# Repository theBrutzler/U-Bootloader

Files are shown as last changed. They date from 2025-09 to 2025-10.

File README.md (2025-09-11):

# U-Bootloader

Learnin PCB with many Sensors. Made in Twitchstream. SUB Tember board!

I created a board!
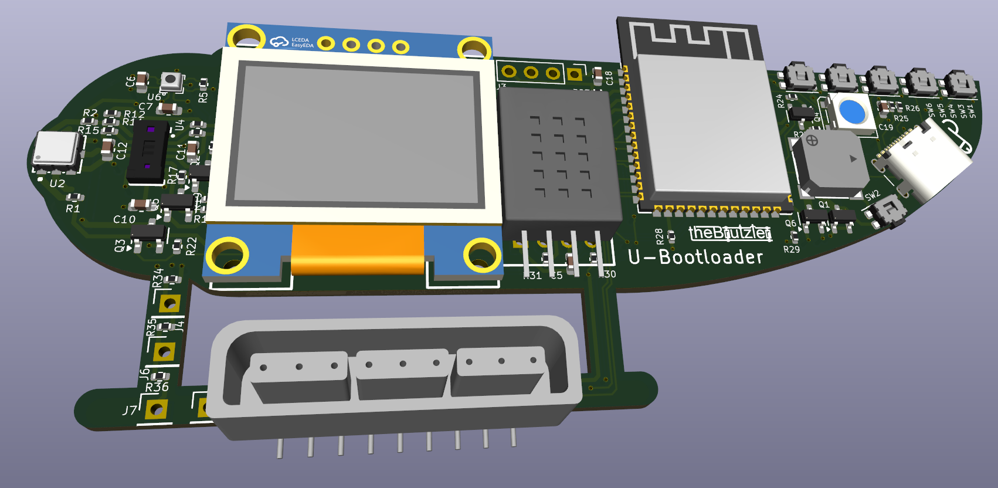
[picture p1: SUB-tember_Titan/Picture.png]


with interesting backside XD

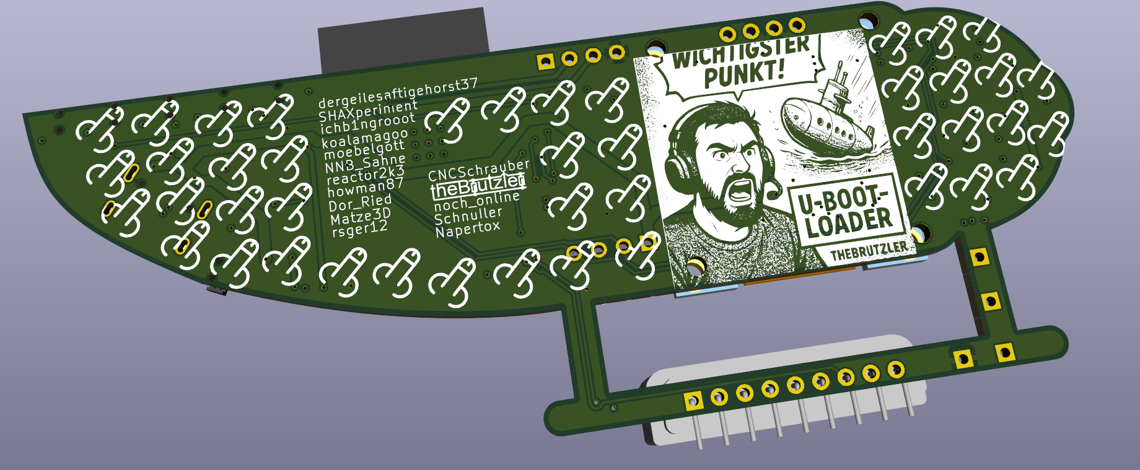
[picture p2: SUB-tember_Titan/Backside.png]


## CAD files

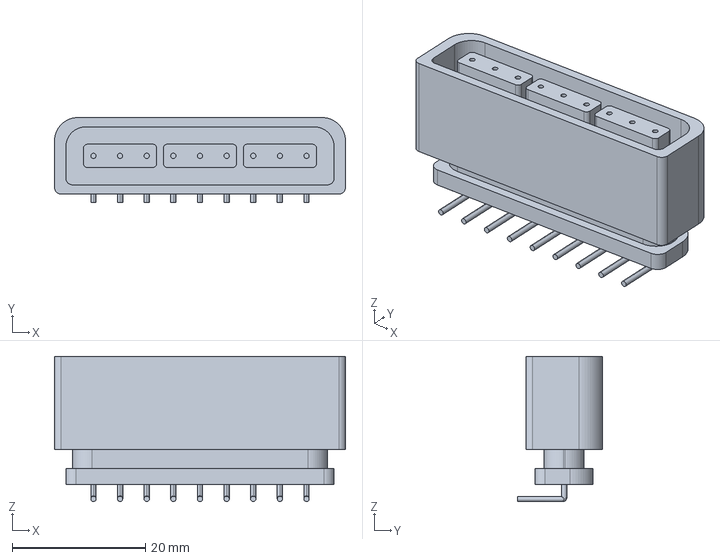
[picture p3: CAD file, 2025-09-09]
SUB-tember_Titan/pritesh.stp
43.7 x 12.8 x 21.8 mm

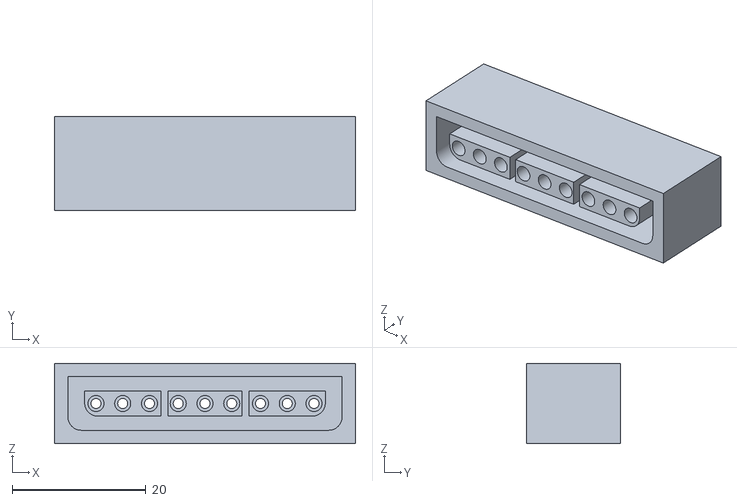
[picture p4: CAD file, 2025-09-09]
SUB-tember_Titan/PS2_Controller_Female_Connector.stl
45.0 x 14.0 x 12.0

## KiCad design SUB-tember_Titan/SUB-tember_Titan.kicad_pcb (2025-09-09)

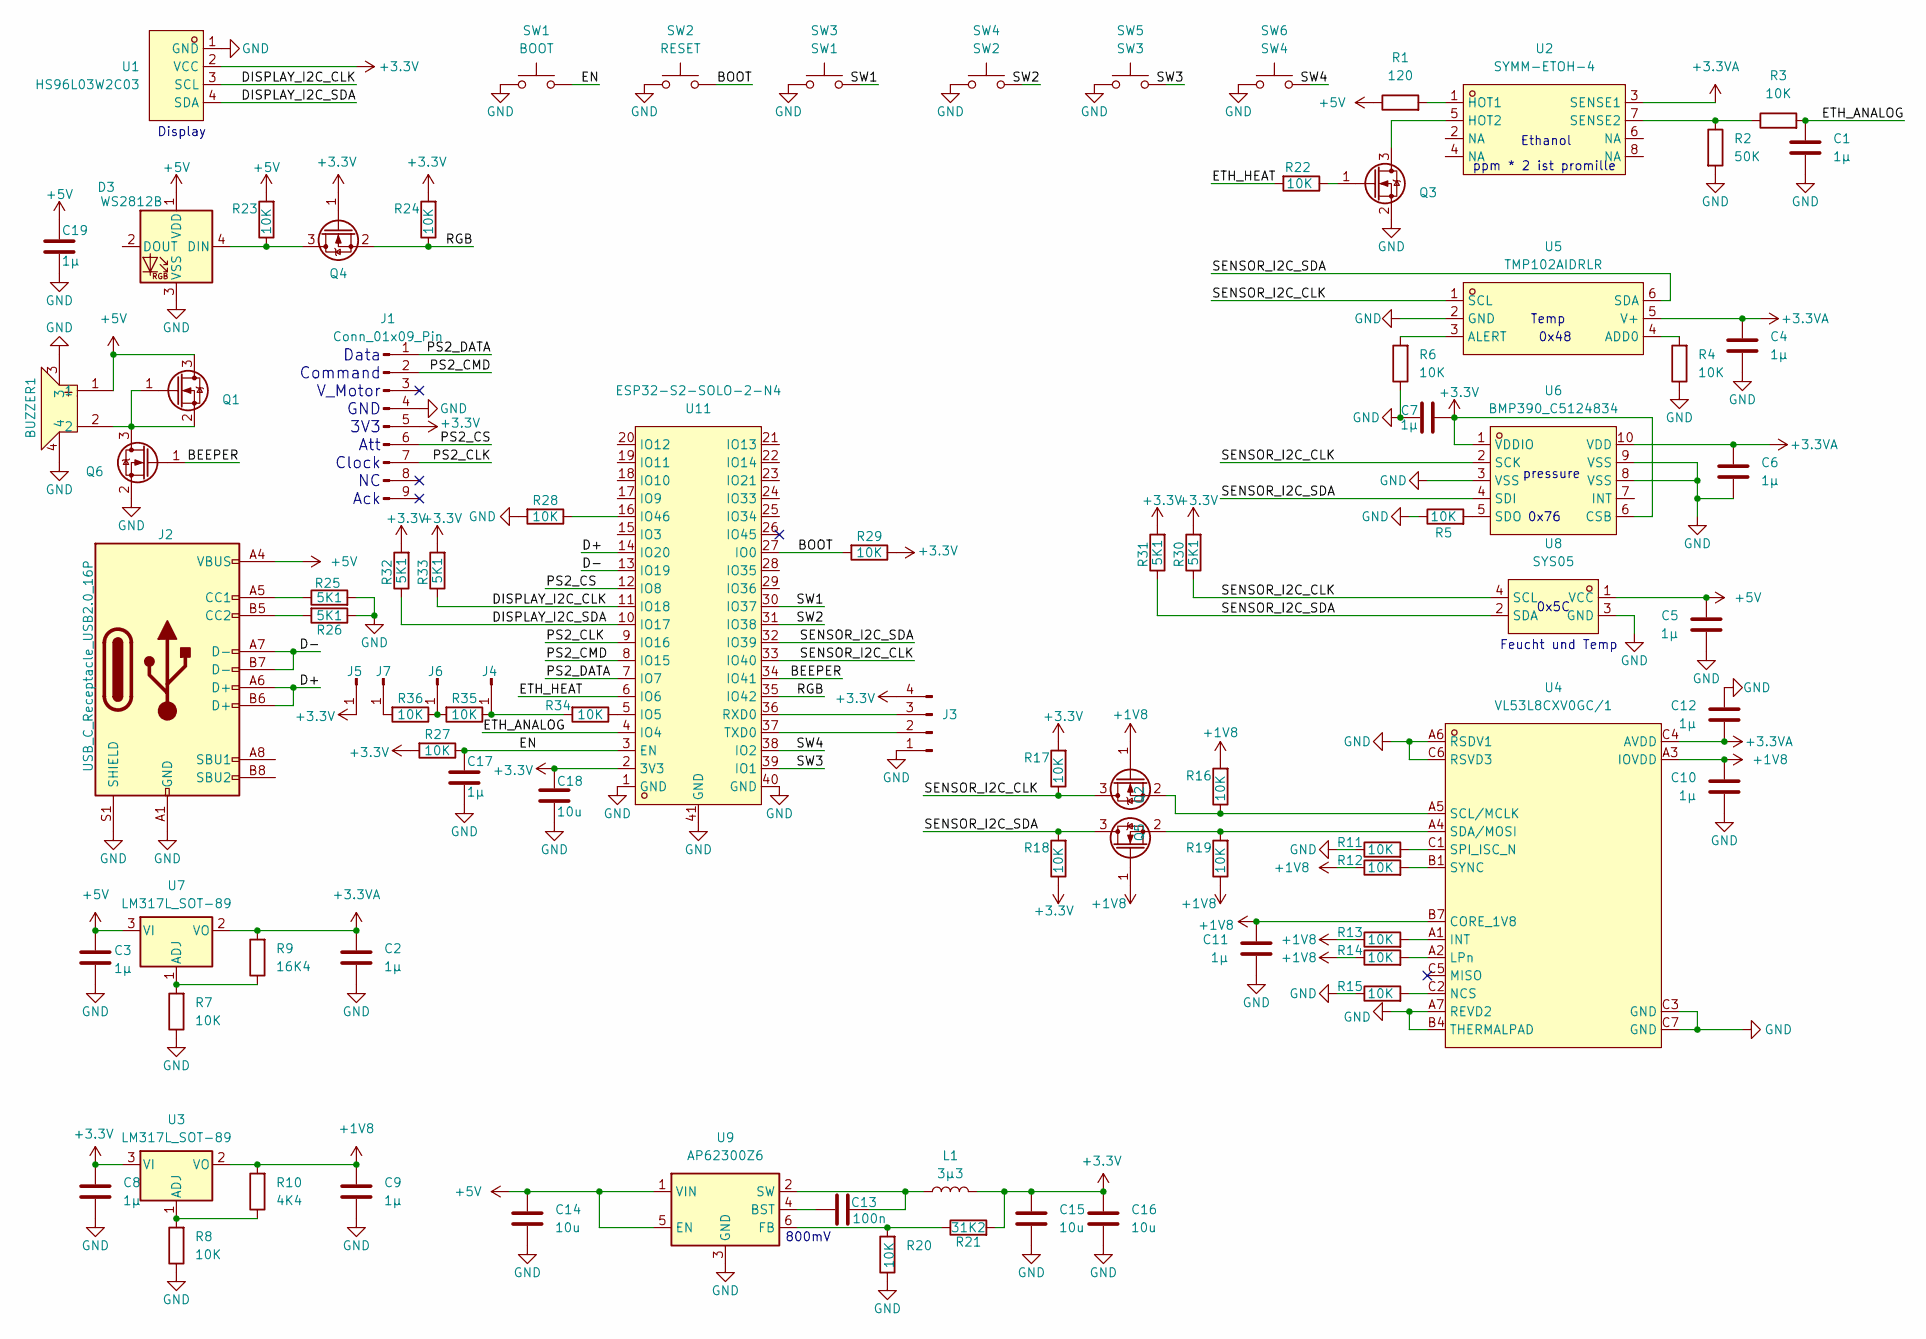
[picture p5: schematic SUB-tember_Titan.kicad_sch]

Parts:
BUZZER1: SMD7525-16Ω; BUZ-SMD_4P-L7.5-W7.5-BR; LCSC Part C49246950
C1, C2, C3, C4, C5, C6, C7, C8, C9, C10, C11, C12, C17, C19: 1µ; C_0603_1608Metric; LCSC Part C6119849
C13: 100n; C_0603_1608Metric; LCSC Part C5137636
C14, C15, C16, C18: 10u; C_0603_1608Metric; LCSC Part C6119842
D3: WS2812B; LED_WS2812B_PLCC4_5.0x5.0mm_P3.2mm; LCSC Part C22461793
J1: Conn_01x09_Pin; PinHeader_1x09_P2.54mm_Vertical
J2: USB_C_Receptacle_USB2.0_16P; USB_C_Receptacle_GCT_USB4105-xx-A_16P_TopMnt_Horizontal; LCSC Part C2927038
J3: Conn_01x04_Pin; PinHeader_1x04_P2.54mm_Vertical
J4, J5, J6, J7: Conn_01x01_Pin; PinHeader_1x01_P2.54mm_Vertical
L1: 3µ3; L_1210_3225Metric; LCSC Part C39846655
Q1, Q2, Q3, Q4, Q5, Q6: Q_NMOS_Depletion_GSD; SOT-23-3; LCSC Part C347475
R1: 120; R_0402_1005Metric; LCSC Part C2909315
R2: 50K; R_0402_1005Metric; LCSC Part C107229
R3, R4, R5, R6, R7, R8, R11, R12, R13, R14, R15, R16, R17, R18, R19, R20, R22, R23, R24, R27, R28, R29, R34, R35, R36: 10K; R_0402_1005Metric; LCSC Part C3017497
R9: 16K4; R_0402_1005Metric; LCSC Part C852558
R10: 4K4; R_0402_1005Metric; LCSC Part C321517
R21: 31K2; R_0402_1005Metric; LCSC Part C2088574
R25, R26, R30, R31, R32, R33: 5K1; R_0402_1005Metric; LCSC Part C2906948
SW1: BOOT; SW_SPST_EVQP7C
SW2: RESET; SW_SPST_EVQP7C
SW3: SW1; SW_SPST_EVQP7C
SW4: SW2; SW_SPST_EVQP7C
SW5: SW3; SW_SPST_EVQP7C
SW6: SW4; SW_SPST_EVQP7C
U1: HS96L03W2C03; OLED-TH_L27.8-W27.2-P2.54_C9900033791; LCSC Part C5248080
U2: SYMM-ETOH-4; LCC-8_L3.8-W3.8-P1.27-BL; LCSC Part C22363926
U3, U7: LM317L_SOT-89; SOT-89-3; LCSC Part C45953613
U4: VL53L8CXV0GC/1; LGA-16_L6.4-W3.0_VL53L5CXV0GC-1; LCSC Part C7386355
U5: TMP102AIDRLR; SOT-563_L1.6-W1.2-P0.50-LS1.6-BR; LCSC Part C99269
U6: BMP390_C5124834; LGA-10_L2.0-W2.0-P0.50-BL; LCSC Part C5124834
U8: SYS05; SIP-4_L12.0-W5.5-P2.54-L; LCSC Part C19727297
U9: AP62300Z6; SOT-563; LCSC Part C5250745
U11: ESP32-S2-SOLO-2-N4; WIRELM-SMD_ESP32-S3-WROOM-1; LCSC Part C3040594

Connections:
+1V8: C9.1, C10.1, C11.1, Q2.1 (G), Q5.1 (G), R10.2, R12.1, R13.1, R14.1, R16.2, R19.1, U3.2 (VO), U4.A3 (IOVDD), U4.B7 (CORE_1V8)
+3.3V: C7.2, C8.1, C15.1, C16.1, C18.1, J1.5, J3.4, J5.1, L1.2, Q4.1 (G), R17.2, R18.1, R21.2, R24.2, R27.2, R29.1, R30.2, R31.2, R32.2, R33.2, U1.2 (VCC), U3.3 (VI), U6.1 (VDDIO), U6.6 (CSB), U11.2 (3V3)
+3.3VA: C2.1, C4.1, C6.1, C12.2, R9.2, U2.3 (SENSE1), U4.C4 (AVDD), U5.5 (V+), U6.10 (VDD), U7.2 (VO)
+5V: BUZZER1.1, C3.1, C5.1, C14.1, C19.1, D3.1 (VDD), J2.A4 (VBUS), J2.A9 (VBUS), J2.B4 (VBUS), J2.B9 (VBUS), Q1.3 (D), R1.1, R23.2, U7.3 (VI), U8.1 (VCC), U9.1 (VIN), U9.5 (EN)
/BEEPER: Q6.1 (G), U11.34 (IO41)
/BOOT: R29.2, SW2.2, U11.27 (IO0)
/D+: J2.A6 (D+), J2.B6 (D+), U11.14 (IO20)
/D-: J2.A7 (D-), J2.B7 (D-), U11.13 (IO19)
/DISPLAY_I2C_CLK: R33.1, U1.3 (SCL), U11.11 (IO18)
/DISPLAY_I2C_SDA: R32.1, U1.4 (SDA), U11.10 (IO17)
/EN: C17.1, R27.1, SW1.2, U11.3 (EN)
/ETH_ANALOG: C1.1, R3.2, U11.4 (IO4)
/ETH_HEAT: R22.2, U11.6 (IO6)
/PS2_CLK: J1.7, U11.9 (IO16)
/PS2_CMD: J1.2, U11.8 (IO15)
/PS2_CS: J1.6, U11.12 (IO8)
/PS2_DATA: J1.1, U11.7 (IO7)
/RGB: Q4.2 (S), R24.1, U11.35 (IO42)
/SENSOR_I2C_CLK: Q5.3 (D), R17.1, R30.1, U5.1 (SCL), U6.2 (SCK), U8.4 (SCL), U11.33 (IO40)
/SENSOR_I2C_SDA: Q2.3 (D), R18.2, R31.1, U5.6 (SDA), U6.4 (SDI), U8.2 (SDA), U11.32 (IO39)
/SW1: SW3.2, U11.30 (IO37)
/SW2: SW4.2, U11.31 (IO38)
/SW3: SW5.2, U11.39 (IO1)
/SW4: SW6.2, U11.38 (IO2)
GND: BUZZER1.3, BUZZER1.4, C1.2, C2.2, C3.2, C4.2, C5.2, C6.2, C7.1, C8.2, C9.2, C10.2, C11.2, C12.1, C14.2, C15.2, C16.2, C17.2, C18.2, C19.2, D3.3 (VSS), J1.4, J2.A1 (GND), J2.A12 (GND), J2.B1 (GND), J2.B12 (GND), J2.S1 (SHIELD), J3.1, Q3.2 (S), Q6.2 (S), R2.2, R4.1, R5.1, R6.1, R7.1, R8.1, R11.1, R15.1, R20.1, R25.2, R26.1, R28.2, SW1.1, SW2.1, SW3.1, SW4.1, SW5.1, SW6.1, U1.1 (GND), U4.A6 (RSDV1), U4.A7 (REVD2), U4.B4 (THERMALPAD), U4.C3 (GND), U4.C6 (RSVD3), U4.C7 (GND), U5.2 (GND), U6.3 (VSS), U6.8 (VSS), U6.9 (VSS), U8.3 (GND), U9.3 (GND), U11.1 (GND), U11.40 (GND), U11.41 (GND)
unnamed: D3.4 (DIN), Q4.3 (D), R23.1
unnamed: J2.A5 (CC1), R25.1
unnamed: J2.B5 (CC2), R26.2
unnamed: J3.2, U11.37 (TXD0)
unnamed: J3.3, U11.36 (RXD0)
unnamed: J4.1, R34.2, R35.1
unnamed: J6.1, R35.2, R36.1
unnamed: J7.1, R36.2
unnamed: BUZZER1.2, Q1.1 (G), Q1.2 (S), Q6.3 (D)
unnamed: Q2.2 (S), R19.2, U4.A4 (SDA/MOSI)
unnamed: Q3.3 (D), U2.5 (HOT2)
unnamed: Q3.1 (G), R22.1
unnamed: Q5.2 (S), R16.1, U4.A5 (SCL/MCLK)
unnamed: R1.2, U2.1 (HOT1)
unnamed: R2.1, R3.1, U2.7 (SENSE2)
unnamed: R8.2, R10.1, U3.1 (ADJ)
unnamed: R13.2, U4.A1 (INT)
unnamed: R14.2, U4.A2 (LPn)
unnamed: R15.2, U4.C2 (NCS)
unnamed: R11.2, U4.C1 (SPI_ISC_N)
unnamed: R12.2, U4.B1 (SYNC)
unnamed: R4.2, U5.4 (ADD0)
unnamed: R6.2, U5.3 (ALERT)
unnamed: R5.2, U6.5 (SDO)
unnamed: R7.2, R9.1, U7.1 (ADJ)
unnamed: C13.1, U9.4 (BST)
unnamed: R20.2, R21.1, U9.6 (FB)
unnamed: C13.2, L1.1, U9.2 (SW)
unnamed: R34.1, U11.5 (IO5)
unnamed: R28.1, U11.16 (IO46)

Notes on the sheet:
Feucht und Temp
Data Command V_Motor GND 3V3 Att Clock NC Ack
Display
800mV
0x76
Ethanol
pressure
Temp
0x48
0x5C
ppm * 2 ist promille

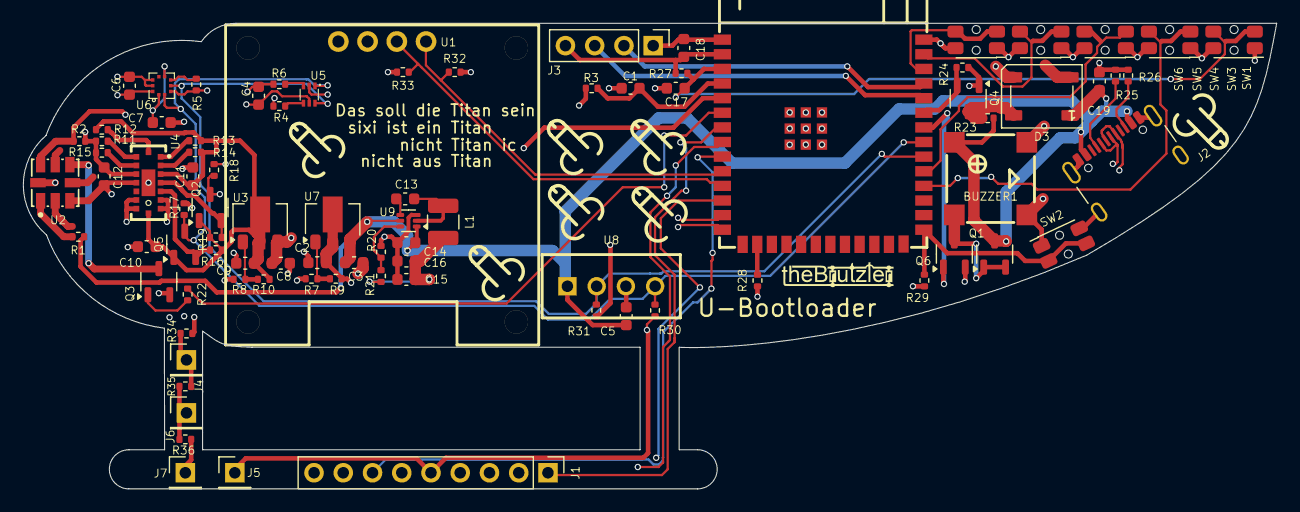
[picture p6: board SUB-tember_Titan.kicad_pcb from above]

Board: 4 copper layers, 108.9 x 40.4 mm, 87 parts (0 on the bottom side), 55 nets.

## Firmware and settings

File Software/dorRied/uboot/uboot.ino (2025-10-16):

#include <Wire.h>
#include <WiFi.h>
#include <WebServer.h>
#include <WebSocketsServer.h>
#include <ArduinoJson.h>
#include <Adafruit_GFX.h>
#include <Adafruit_SSD1306.h>
#include <SparkFunTMP102.h>
#include <Adafruit_Sensor.h>
#include <Adafruit_BMP3XX.h>
#include <vl53l8cx.h>
#include "Freenove_WS2812_Lib_for_ESP32.h"
#include "SP3SAQ2.h"
#include <block.h>

// Display Configuration
#define OLED_SDA 17
#define OLED_SCL 18
#define SCREEN_WIDTH 128
#define SCREEN_HEIGHT 64
#define OLED_RESET -1
Adafruit_SSD1306 display(SCREEN_WIDTH, SCREEN_HEIGHT, &Wire1, OLED_RESET);

// Brutzel Kurzschluss BlockIntro
int y = 0;
int x = 0;

// I2C Sensors Configuration
#define Sensor_SDA 39
#define Sensor_SCL 40

// RGB LED Configuration
#define LEDS_COUNT 1
#define LEDS_PIN 42
#define CHANNEL 0
Freenove_ESP32_WS2812 strip = Freenove_ESP32_WS2812(LEDS_COUNT, LEDS_PIN, CHANNEL, TYPE_GRB);

// Ethanol Sensor Configuration
#define ADC_BIT_RESU 12
#define ETHANOL_PIN 4
#define ETH_HEAT 6
float sensorVal, ethanol_ppm, ethanol_old , ethanol_avg;
float ethanol[100];
SP3SAQ2 sensor(ADC_BIT_RESU, ETHANOL_PIN);

// TMP102 Temperature Sensor
TMP102 sensor_tmp;

// BMP390 Pressure Sensor
#define SEALEVELPRESSURE_HPA 1024.25  // fits best for me -- checked with https://whatismyelevation.com/ and https://www.mide.com/air-pressure-at-altitude-calculator
Adafruit_BMP3XX BMP390;

// VL53L8CX TOF Sensor Configuration - https://www.st.com/en/imaging-and-photonics-solutions/vl53l8cx.html - nice one - now I understand the price :)
#define LPN_PIN -1
#define PWREN_PIN -1
VL53L8CX sensor_vl53l8cx(&Wire, LPN_PIN);
uint8_t status;
uint8_t res = VL53L8CX_RESOLUTION_8X8;
bool EnableAmbient = false;
bool EnableSignal = false;
int distances[8][8];
int prevDistances[8][8];
int centerDistance = 0;
const int motionThreshold = 70;  // give it bit more tolerance otherwise there are too much "false" detections
bool motionDetected = false;

// WiFi AP Configuration
const char* ssid = "Titan";
const char* password = "titan123";

// Web Server and WebSocket
WebServer server(80);
WebSocketsServer webSocket = WebSocketsServer(81);

// Sensor Data Variables
float temperature = 0;
float temperature_bosch = 0;
float pressure = 0;
float altitude = 0;
unsigned long lastSensorUpdate = 0;
unsigned long lastDisplayUpdate = 0;
unsigned long lastWebUpdate = 0;
const unsigned long SENSOR_UPDATE_INTERVAL = 500;
const unsigned long DISPLAY_UPDATE_INTERVAL = 100;
const unsigned long WEB_UPDATE_INTERVAL = 50;

// HTML Web Page with Twitch-themed colors
const char index_html[] PROGMEM = R"rawliteral(
<!DOCTYPE html>
<html lang="en">
<head>
    <meta charset="UTF-8">
    <meta name="viewport" content="width=device-width, initial-scale=1.0">
    <title>Titan Sensor Dashboard</title>
    <style>
        * {
            margin: 0;
            padding: 0;
            box-sizing: border-box;
        }
        
        body {
            font-family: 'Inter', -apple-system, BlinkMacSystemFont, 'Segoe UI', Roboto, sans-serif;
            background: #0e0e10;
            color: #efeff1;
            padding: 20px;
            line-height: 1.6;
        }
        
        .container {
            max-width: 1200px;
            margin: 0 auto;
        }
        
        h1 {
            color: #9147ff;
            text-align: center;
            margin-bottom: 30px;
            font-size: 2.5em;
            text-shadow: 0 0 20px rgba(145, 71, 255, 0.5);
        }
        
        .dashboard {
            display: grid;
            grid-template-columns: repeat(auto-fit, minmax(300px, 1fr));
            gap: 20px;
            margin-bottom: 30px;
        }
        
        .sensor-card {
            background: #18181b;
            border: 1px solid #2d2d30;
            border-radius: 8px;
            padding: 20px;
            transition: all 0.3s ease;
            box-shadow: 0 4px 6px rgba(0, 0, 0, 0.3);
        }
        
        .sensor-card:hover {
            transform: translateY(-5px);
            border-color: #9147ff;
            box-shadow: 0 6px 20px rgba(145, 71, 255, 0.2);
        }
        
        .sensor-title {
            color: #9147ff;
            font-size: 1.2em;
            margin-bottom: 15px;
            font-weight: 600;
            display: flex;
            align-items: center;
            gap: 10px;
        }
        
        .sensor-value {
            font-size: 2em;
            font-weight: bold;
            color: #efeff1;
            margin: 10px 0;
            text-align: center;
            padding: 15px;
            background: #0e0e10;
            border-radius: 6px;
            border: 1px solid #2d2d30;
        }
        
        .unit {
            font-size: 0.5em;
            color: #adadb8;
            margin-left: 5px;
        }
        
        .tof-container {
            grid-column: span 2;
            background: #18181b;
            border: 1px solid #2d2d30;
            border-radius: 8px;
            padding: 20px;
            box-shadow: 0 4px 6px rgba(0, 0, 0, 0.3);
            margin-top: 20px;
        }
        
        #tofCanvas {
            width: 100%;
            max-width: 600px;
            margin: 20px auto;
            display: block;
            border: 2px solid #9147ff;
            border-radius: 8px;
            background: #0e0e10;
            box-shadow: 0 0 30px rgba(145, 71, 255, 0.3);
        }
        
        .status {
            display: inline-block;
            width: 10px;
            height: 10px;
            border-radius: 50%;
            background: #00f593;
            animation: pulse 2s infinite;
        }
        
        .status.offline {
            background: #ff4444;
            animation: none;
        }
        
        @keyframes pulse {
            0% { box-shadow: 0 0 0 0 rgba(0, 245, 147, 0.7); }
            70% { box-shadow: 0 0 0 10px rgba(0, 245, 147, 0); }
            100% { box-shadow: 0 0 0 0 rgba(0, 245, 147, 0); }
        }
        
        .motion-indicator {
            text-align: center;
            padding: 10px;
            margin-top: 10px;
            background: #0e0e10;
            border-radius: 6px;
            border: 1px solid #2d2d30;
            transition: all 0.3s ease;
        }
        
        .motion-indicator.active {
            background: #9147ff;
            color: white;
            border-color: #9147ff;
            animation: flash 0.5s;
        }
        
        @keyframes flash {
            0%, 100% { opacity: 1; }
            50% { opacity: 0.5; }
        }
        
        .legend {
            display: flex;
            justify-content: center;
            gap: 30px;
            margin-top: 15px;
            flex-wrap: wrap;
        }
        
        .legend-item {
            display: flex;
            align-items: center;
            gap: 8px;
            font-size: 0.9em;
            color: #adadb8;
        }
        
        .legend-color {
            width: 20px;
            height: 20px;
            border-radius: 4px;
            border: 1px solid #2d2d30;
        }
        
        .connection-status {
            text-align: center;
            margin-bottom: 20px;
            padding: 10px;
            background: #18181b;
            border-radius: 8px;
            border: 1px solid #2d2d30;
        }
    </style>
</head>
<body>
    <div class="container">
        <h1>Titan Sensor Dashboard</h1>
        
        <div class="connection-status">
            <span class="status" id="connectionStatus"></span>
            <span id="connectionText">Connected</span>
        </div>
        
        <div class="dashboard">
            <div class="sensor-card">
                <div class="sensor-title">
                    🌡️ Temperature Texas (TI)
                </div>
                <div class="sensor-value" id="temperature">
                    --<span class="unit">°C</span>
                </div>
            </div>
            
            <div class="sensor-card">
                <div class="sensor-title">
                    🌡️ Temperature Bosch
                </div>
                <div class="sensor-value" id="temperature_bosch">
                    --<span class="unit">°C</span>
                </div>
            </div>

            <div class="sensor-card">
                <div class="sensor-title">
                    ⛰️ Altitude
                </div>
                <div class="sensor-value" id="altitude">
                    --<span class="unit">m</span>
                </div>
            </div>
            
            <div class="sensor-card">
                <div class="sensor-title">
                    🌪️ Pressure
                </div>
                <div class="sensor-value" id="pressure">
                    --<span class="unit">bar</span>
                </div>
            </div>

            <div class="sensor-card">
                <div class="sensor-title">
                    🔬 Ethanol
                </div>
                <div class="sensor-value" id="ethanol">
                    --<span class="unit">ppm</span>
                </div>
            </div>
        </div>
        
        <div class="tof-container">
            <div class="sensor-title">
                VL53L8CX Sensor
            </div>
            <canvas id="tofCanvas" width="400" height="400"></canvas>
            <div class="motion-indicator" id="motionIndicator">
                No Motion Detected
            </div>
            <div class="legend">
                <div class="legend-item">
                    <div class="legend-color" style="background: #0000ff;"></div>
                    <span>Near (< 500mm)</span>
                </div>
                <div class="legend-item">
                    <div class="legend-color" style="background: #00ff00;"></div>
                    <span>Medium (500-1500mm)</span>
                </div>
                <div class="legend-item">
                    <div class="legend-color" style="background: #ff0000;"></div>
                    <span>Far (> 1500mm)</span>
                </div>
            </div>
        </div>
    </div>
    
    <script>
        let ws;
        const canvas = document.getElementById('tofCanvas');
        const ctx = canvas.getContext('2d');
        const cellSize = canvas.width / 8;
        
        function connectWebSocket() {
            ws = new WebSocket('ws://' + window.location.hostname + ':81/');
            
            ws.onopen = function() {
                console.log('WebSocket connected');
                document.getElementById('connectionStatus').classList.remove('offline');
                document.getElementById('connectionText').textContent = 'Connected';
            };
            
            ws.onclose = function() {
                console.log('WebSocket disconnected');
                document.getElementById('connectionStatus').classList.add('offline');
                document.getElementById('connectionText').textContent = 'Disconnected - Reconnecting...';
                setTimeout(connectWebSocket, 3000);
            };
            
            ws.onerror = function(error) {
                console.error('WebSocket error:', error);
            };
            
            ws.onmessage = function(event) {
                try {
                    const data = JSON.parse(event.data);
                    updateSensorData(data);
                } catch(e) {
                    console.error('Failed to parse data:', e);
                }
            };
        }
        
        function updateSensorData(data) {
            if (data.temperature !== undefined) {
                document.getElementById('temperature').innerHTML = 
                    data.temperature.toFixed(1) + '<span class="unit">°C</span>';
            }
            if (data.temperature_bosch !== undefined) {
                document.getElementById('temperature_bosch').innerHTML = 
                    data.temperature_bosch.toFixed(1) + '<span class="unit">°C</span>';
            }
            if (data.ethanol !== undefined) {
                document.getElementById('ethanol').innerHTML = 
                    data.ethanol.toFixed(2) + '<span class="unit">ppm</span>';
            }
            if (data.bac !== undefined) {
                document.getElementById('bac').innerHTML = 
                    data.bac.toFixed(2) + '<span class="unit">‰</span>';
            }
            if (data.pressure !== undefined) {
                document.getElementById('pressure').innerHTML = 
                    data.pressure.toFixed(1) + '<span class="unit">bar</span>';
            }
            if (data.altitude !== undefined) {
                document.getElementById('altitude').innerHTML = 
                    data.altitude.toFixed(1) + '<span class="unit">m</span>';
            }
            if (data.tof !== undefined) {
                drawTOFGrid(data.tof);
            }
            if (data.motion !== undefined) {
                const indicator = document.getElementById('motionIndicator');
                if (data.motion) {
                    indicator.textContent = 'Motion Detected!';
                    indicator.classList.add('active');
                } else {
                    indicator.textContent = 'No Motion Detected';
                    indicator.classList.remove('active');
                }
            }
        }
        
        function drawTOFGrid(distances) {
            ctx.clearRect(0, 0, canvas.width, canvas.height);
            
            for (let y = 0; y < 8; y++) {
                for (let x = 0; x < 8; x++) {
                    const distance = distances[y][x];
                    const color = getColorForDistance(distance);
                    
                    ctx.fillStyle = color;
                    ctx.fillRect(x * cellSize, y * cellSize, cellSize - 2, cellSize - 2);
                    
                    ctx.fillStyle = '#ffffff';
                    ctx.font = '12px Arial';
                    ctx.textAlign = 'center';
                    ctx.fillText(distance + 'mm', x * cellSize + cellSize/2, y * cellSize + cellSize/2);
                }
            }
        }
        
        function getColorForDistance(distance) {
            if (distance < 500) {
                return `rgba(0, 0, 255, ${1 - (distance / 500) * 0.5})`;
            } else if (distance < 1500) {
                return `rgba(0, 255, 0, ${1 - ((distance - 500) / 1000) * 0.5})`;
            } else {
                return `rgba(255, 0, 0, 0.5)`;
            }
        }
        
        connectWebSocket();
    </script>
</body>
</html>
)rawliteral";
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
void loop() {
  server.handleClient();
  webSocket.loop();

  unsigned long currentMillis = millis();

  // Update sensors
  if (currentMillis - lastSensorUpdate >= SENSOR_UPDATE_INTERVAL) {
    lastSensorUpdate = currentMillis;
    updateSensors();
  }

  // Update display
  if (currentMillis - lastDisplayUpdate >= DISPLAY_UPDATE_INTERVAL) {
    lastDisplayUpdate = currentMillis;
    updateOLED();
  }

  // Send data to web clients
  if (currentMillis - lastWebUpdate >= WEB_UPDATE_INTERVAL) {
    lastWebUpdate = currentMillis;
    sendSensorData();
  }
}

void updateSensors() {
  static bool tmpAvailable = true;
  if (tmpAvailable) {
    sensor_tmp.oneShot(1);
    float newTemp = sensor_tmp.readTempC();
    if (newTemp > -40 && newTemp < 125) {
      temperature = newTemp;
    } else {
      tmpAvailable = false;
    }
  }
  if(x<100){
    sensorVal = sensor.read();
    ethanol[x] = sensorVal;
  }
  else{
    x = 0;
  }
  for(int i=0;i<100;i++){
    ethanol_avg+=ethanol[i];
  }
  ethanol_avg=ethanol_avg/100;
 

  // Ethanol calculation - must be tested - not linear - https://www.saiyasensor.com/res/soft/2024/22e2933ca620c575.pdf

  ethanol_ppm = ((sensorVal - (ethanol_avg))+0.15) / 1.5;
  ethanol_avg = sensorVal;
  if (ethanol_ppm < 0) ethanol_ppm = 0;
  if (ethanol_ppm>ethanol_old) ethanol_old = ethanol_ppm;

  // Read BMP390
  BMP390.performReading();
  float pressure_hPa = BMP390.pressure / 100.0;  // hPa;
  pressure = (pressure_hPa/1000),2;            //  hPa to bar
  altitude = BMP390.readAltitude(SEALEVELPRESSURE_HPA);
  temperature_bosch = BMP390.temperature;     // when I would divide by 1.7 it roughly fits my room temperature - but yes the board is "warm" thats for sure so measured temps should fit - TI and Bosch - same story

  // Read VL53L8CX
  updateVL53L8CXSensor();
}

void updateVL53L8CXSensor() {
  VL53L8CX_ResultsData results;
  uint8_t isReady = 0;

  sensor_vl53l8cx.check_data_ready(&isReady);

  if (isReady) {
    sensor_vl53l8cx.get_ranging_data(&results);

    // Store previous distances for motion detection
    memcpy(prevDistances, distances, sizeof(distances));

    // Update current distances
    int index = 0;
    motionDetected = false;

    for (int y = 0; y < 8; y++) {
      for (int x = 0; x < 8; x++) {
        distances[y][x] = results.distance_mm[index];

        // Check for motion
        if (abs(distances[y][x] - prevDistances[y][x]) > motionThreshold) {
          motionDetected = true;
        }
        index++;
      }
    }

    // Get center distance (average of center 4 zones)
    centerDistance = (distances[3][3] + distances[3][4] + distances[4][3] + distances[4][4]) / 4;

    // Update LED based on center distance
    updateLEDByDistance(centerDistance);
  }
}

void updateLEDByDistance(int distance) {
  if (distance < 500) {
    setStatusLED(0, 0, 255);  // Blue for close
  } else if (distance < 1000) {
    setStatusLED(0, 255, 0);  // Green for medium
  } else if (distance < 1500) {
    setStatusLED(255, 255, 0);  // Yellow for far
  } else {
    setStatusLED(255, 0, 0);  // Red for very far
  }
}

void setStatusLED(uint8_t r, uint8_t g, uint8_t b) {
  strip.setLedColorData(0, r, g, b);
  strip.show();
}

void updateOLED() {
  display.clearDisplay();
  display.setTextSize(1);
  display.setTextColor(SSD1306_WHITE);

  display.setCursor(0, 0);
  display.println("== TITAN SENSORS ==");

  display.setCursor(0, 16);
  display.print("Temp: ");
  display.print(temperature, 1);
  display.println(" C");

  display.setCursor(0, 26);
  display.print("Ethanol: ");
  display.print(sensorVal, 2);
  display.println(" ppm");

  display.print("Ethanol: ");
  display.print(ethanol_old, 2);
  display.println(" max");
  

  //display.setCursor(0, 36);
  //display.print("Pressure: ");
  //display.print(pressure, 2);
  //display.println(" bar");

  display.setCursor(0, 46);
  display.print("Alt: ");
  display.print(altitude, 1);
  display.println(" m");

  display.setCursor(0, 56);
  display.print("Dist: ");
  display.print(centerDistance);
  display.print("mm ");

  if (motionDetected) {
    display.print("[MOTION]");
  }

  display.display();
}

void updateDisplay(String line1, String line2, String line3) {
  display.clearDisplay();
  display.setTextSize(1);
  display.setTextColor(SSD1306_WHITE);

  display.setCursor(0, 0);
  display.println(line1);
  display.setCursor(0, 20);
  display.println(line2);
  display.setCursor(0, 40);
  display.println(line3);

  display.display();
}

void sendSensorData() {
  if (webSocket.connectedClients() > 0) {
    StaticJsonDocument<1024> doc;

    doc["temperature"] = temperature;
    doc["temperature_bosch"] = temperature_bosch;
    doc["ethanol"] = sensorVal;
    doc["pressure"] = pressure;
    doc["altitude"] = altitude;
    doc["motion"] = motionDetected;

    // Add VL53L8CX data
    JsonArray tofArray = doc.createNestedArray("tof");
    for (int y = 0; y < 8; y++) {
      JsonArray row = tofArray.createNestedArray();
      for (int x = 0; x < 8; x++) {
        row.add(distances[y][x]);
      }
    }

    String jsonString;
    serializeJson(doc, jsonString);
    webSocket.broadcastTXT(jsonString);
  }
}

void webSocketEvent(uint8_t num, WStype_t type, uint8_t* payload, size_t length) {
  switch (type) {
    case WStype_DISCONNECTED:
      Serial.printf("[%u] Disconnected!\n", num);
      break;
    case WStype_CONNECTED:
      {
        IPAddress ip = webSocket.remoteIP(num);
        Serial.printf("[%u] Connected from %d.%d.%d.%d\n", num, ip[0], ip[1], ip[2], ip[3]);
      }
      break;
    case WStype_TEXT:
      Serial.printf("[%u] Received text: %s\n", num, payload);
      break;
    case WStype_BIN:
      Serial.printf("[%u] Received binary length: %u\n", num, length);
      break;
  }
}

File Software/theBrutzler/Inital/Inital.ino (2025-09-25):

#include <Wire.h>
#include <Adafruit_GFX.h>
#include <Adafruit_SSD1306.h>

// Display
#include <block.h>
#define OLED_SDA 17
#define OLED_SCL 18
Adafruit_SSD1306 display(128, 64, &Wire1); //, OLED_RESET);

int y = 0;
int x = 0;

// RGB LED
#include "Freenove_WS2812_Lib_for_ESP32.h"
#define LEDS_COUNT  1
#define LEDS_PIN	42
#define CHANNEL		0
Freenove_ESP32_WS2812 strip = Freenove_ESP32_WS2812(LEDS_COUNT, LEDS_PIN, CHANNEL, TYPE_GRB);
uint8_t m_color[5][3] = { {255, 0, 0}, {0, 255, 0}, {0, 0, 255}, {255, 255, 255}, {0, 0, 0} };
int delayval = 100;

//ETHANOL
#include "SP3SAQ2.h"
#define ADC_BIT_RESU (12) // for ESP32
#define pin          (4)  // D4 (ADC1)
float sensorVal, Ethanol;
SP3SAQ2 sensor(ADC_BIT_RESU, pin);
#define ETH_HEAT 6

//I2C_Sensors
#define Sensor_SDA 39
#define Sensor_SCL 40


//TMP102
#include <SparkFunTMP102.h> // Used to send and recieve specific information from our sensor
TMP102 sensor0;

//BMP390
#include <Adafruit_Sensor.h>
#include <Adafruit_BMP3XX.h>
#define SEALEVELPRESSURE_HPA (1013.25)
Adafruit_BMP3XX BMP390;

//VL53L8
#include <vl53l8cx.h>
#define LPN_PIN -1
#define PWREN_PIN -1
VL53L8CX sensor_vl53l8cx_top(&Wire, LPN_PIN);
uint8_t status;
bool EnableAmbient = false;
bool EnableSignal = false;
char report[256];
uint8_t res = VL53L8CX_RESOLUTION_4X4;

void setup() {
  // put your setup code here, to run once:
  Serial.begin(115200); 
  pinMode(ETH_HEAT, OUTPUT);
  digitalWrite(ETH_HEAT, HIGH);
  delay(2000);
  Serial.print("Starting\n");

  //Display
  Wire1.begin(OLED_SDA, OLED_SCL);
  display.begin(SSD1306_SWITCHCAPVCC, 0x3C, false, false);
  Serial.print("Display done\n");

  //RGB
	strip.begin();
	strip.setLedColorData(0, 10, 0, 0);
	strip.setBrightness(10);
	strip.show();
  Serial.print("RGB done\n");

  //ETHANOL
  sensor.begin(); 
  Serial.print("ETH done\n");

  //I2C Sensors
  Wire.begin(Sensor_SDA,Sensor_SCL);
  sensor0.begin(0x48, Wire);  
  Serial.print("I2C done\n");

  //VL53L8
  sensor_vl53l8cx_top.set_i2c_address(0x29);
  sensor_vl53l8cx_top.begin();
  status = sensor_vl53l8cx_top.init();
  Serial.print("VL53 done\n");

  //BMP390
  BMP390.begin_I2C(0x76,&Wire);


  while (y < 64)
  {
    display.clearDisplay();
    display.setTextColor(WHITE);
    display.setCursor(0, 0);
    display.print(F(" U-BOOTLOADER "));
    display.drawBitmap(34, 10, block[x], 54, 54, WHITE);
    display.display();
    delay(100);
    if (x == 13)
      x = 0;
    else
      x++;
    y++;
  }
  display.clearDisplay();
  display.display();

  
  Serial.print("Setup done\n");

}

void loop() {
    display.clearDisplay();
    Serial.print("Loop Start\n");

    //ETHANOL
    sensorVal = sensor.read();
    Serial.print(F(" Ethanol raw: "));
    Serial.println(sensorVal);
    Ethanol = (sensorVal-0.55)/1.5;
    if(Ethanol<=0)
      Ethanol = 0;
    display.setCursor(0, 0);
    display.print(F(" Ethanol: "));
    display.println(Ethanol);

    Serial.print(F(" Ethanol: "));
    Serial.println(Ethanol);
    Serial.print("Ethanol END\n");
    
    //TMP102
    sensor0.oneShot(1); // Set One-Shot bit
    //while(sensor0.oneShot() == 0); // Wait for conversion to be ready

    Serial.print(F(" TempT: "));
    Serial.println(sensor0.readTempC());  // Print temperature reading
      
    display.print(F(" TempT: "));
    display.println(sensor0.readTempC());  // Print temperature reading

    //BMP390
    BMP390.performReading();
    float temp = BMP390.temperature;         // °C
    float pressure_hPa = BMP390.pressure / 100.0;  // hPa
    float altitude_m = BMP390.readAltitude(SEALEVELPRESSURE_HPA);  // Höhe über NN
    display.print(" TempB: ");
    display.print(temp); // Print with 2 decimal places
    display.println(" C");
    display.print(" PressB: ");
    display.print((pressure_hPa/1000),2); // Convert Pa to hPa (hectopascals)
    display.println(" Bar");
    display.print(" AltB: ");
    display.println(altitude_m);
    display.display();

    Serial.print(" TempB: ");
    Serial.print(temp); // Print with 2 decimal places
    Serial.println(" °C");
    Serial.print(" Pressure: ");
    Serial.print((pressure_hPa/1000),2); // Convert Pa to hPa (hectopascals)
    Serial.println(" Bar");

    //VL53L8C
    VL53L8CX_ResultsData Results;
    uint8_t NewDataReady = 0;
    
    Serial.print("Sensor Start\n");

      sensor_vl53l8cx_top.get_ranging_data(&Results);
      print_result(&Results);
    Serial.print("Sensor END\n");
    display.display();

    delay(1000);


}

void print_result(VL53L8CX_ResultsData *Result)
{
  int8_t i, j, k;
  uint8_t l, zones_per_line;
  uint8_t number_of_zones = res;

  zones_per_line = (number_of_zones == 16) ? 4 : 8;

  Serial.print("Cell Format :\n\n");

  for (l = 0; l < VL53L8CX_NB_TARGET_PER_ZONE; l++) {
    snprintf(report, sizeof(report), " \033[38;5;10m%20s\033[0m : %20s\n", "Distance [mm]", "Status");
    Serial.print(report);

    if (EnableAmbient || EnableSignal) {
      snprintf(report, sizeof(report), " %20s : %20s\n", "Signal [kcps/spad]", "Ambient [kcps/spad]");
      Serial.print(report);
    }
  }

  Serial.print("\n\n");

  for (j = 0; j < number_of_zones; j += zones_per_line) {
    for (i = 0; i < zones_per_line; i++) {
      Serial.print(" -----------------");
    }
    Serial.print("\n");

    for (i = 0; i < zones_per_line; i++) {
      Serial.print("|                 ");
    }
    Serial.print("|\n");

    for (l = 0; l < VL53L8CX_NB_TARGET_PER_ZONE; l++) {
      // Print distance and status
      for (k = (zones_per_line - 1); k >= 0; k--) {
        if (Result->nb_target_detected[j + k] > 0) {
          snprintf(report, sizeof(report), "| \033[38;5;10m%5ld\033[0m  :  %5ld ",
                   (long)Result->distance_mm[(VL53L8CX_NB_TARGET_PER_ZONE * (j + k)) + l],
                   (long)Result->target_status[(VL53L8CX_NB_TARGET_PER_ZONE * (j + k)) + l]);
          Serial.print(report);
        } else {
          snprintf(report, sizeof(report), "| %5s  :  %5s ", "X", "X");
          Serial.print(report);
        }
      }
      Serial.print("|\n");
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

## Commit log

2025-09-09 inital upload
    [PS2_Controller_Female_Connector.stl, SUB-tember_Titan.kicad_pcb, SUB-tember_Titan.kicad_sch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]
2025-09-25 update software and html bom
